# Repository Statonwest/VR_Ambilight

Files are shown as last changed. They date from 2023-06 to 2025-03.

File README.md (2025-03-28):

## Introduction

The VR Ambilight is a project that enhances the immersive experience of virtual reality (VR) by creating dynamic ambient lighting that synchronizes with the on-screen content. This guide will walk you through the process of building your own VR Ambilight system.

V1

It performs exceptionally well for games that feature vibrant colors, like Beat Saber.

## Features

Dynamic ambient lighting synchronized with VR content.

Adjustable color and brightness settings.

Support for Valve Index.

## Materials

Arduino Nano

WS2812b Individually Addressable led Strip 144Pixels/m

Soldering equipment

Defusion sheet

---
Alternative 3D printed diffuser:

Clear filament

Paper

Glue

## Wiring Diagram

Ensure that the LED strip you are using operates at a voltage of **5V**.
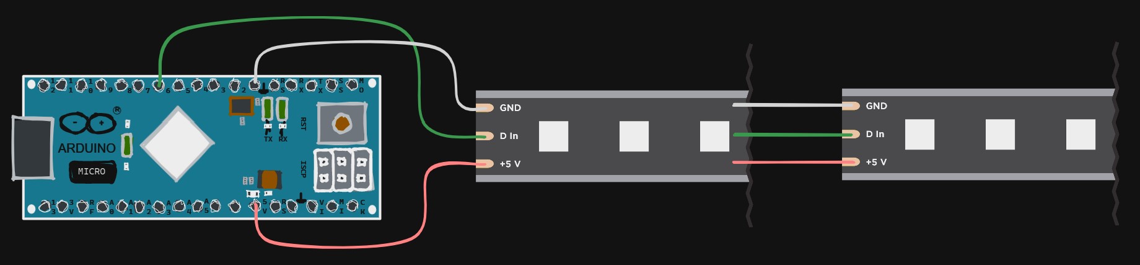
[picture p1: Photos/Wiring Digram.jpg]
Wiring Digram

Typically, for larger LED strip setups, it would require a separate power supply unit (PSU). However, in this case, the number of LEDs is small enough to be powered directly from the Arduino board itself.

## Arduino Setup

Download and install the Arduino IDE from the official Arduino website (https://www.arduino.cc/en/software).

Install the [FastLED libruary](https://github.com/FastLED/FastLED/releases).

Clone or download the project files from the GitHub repository:
[VR_Ambient_light.ino](https://github.com/Statonwest/VR_Ambilight/blob/4264298c710a5be8f2513a294410e2fc3ae0b779/VR_Ambient_light.ino)

The original repository can be found here.
[adalight.ino](https://github.com/hyperion-project/hyperion.ng/blob/master/assets/firmware/arduino/adalight/adalight.ino)

## Building the VR Ambilight

Cut two LED strips, each with 9 LEDs.

Solder the two individual strips together using wire lengths that are long enough to route around to each side of the face gasket.

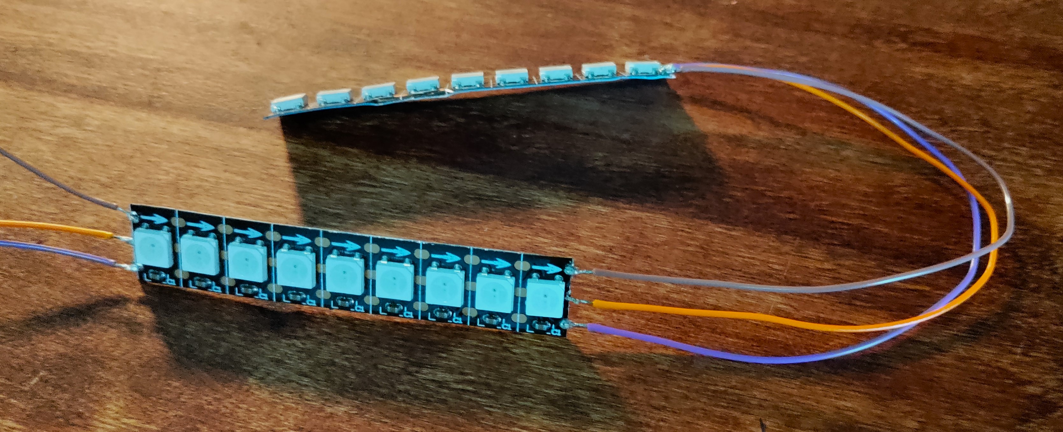
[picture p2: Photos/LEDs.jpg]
Leds


Connect the data line, GND, and the 5V of the LED strip to the Arduino. Connect the DIN (data input) pin of the LED strip to digital pin 6 on the Arduino.

Double-check all the connections to ensure they are secure.

Position the LED strip on the sides of your face gasket, ensuring an even distribution of light. Refer to the image below for reference:

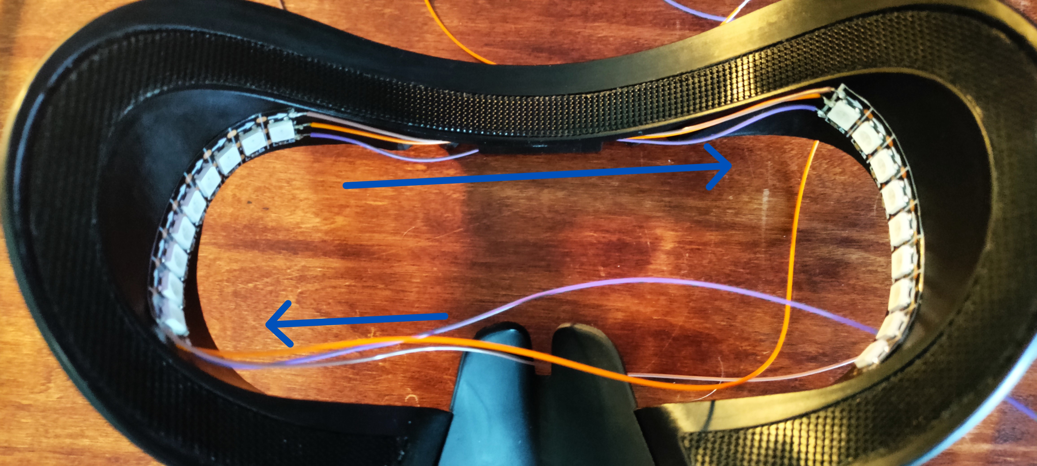
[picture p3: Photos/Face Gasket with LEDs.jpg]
Face Gasket wireing


Choose a wire routing method that works best for you. I opted to route the wires from underneath and over the top of the gasket, but there are other possible arrangements. Adjust your Prismatik settings accordingly to match your wire placement. 

Mount the Arduino Nano securely at the front of the index. Connect the Arduino Nano to the USB port for power and data transmission.

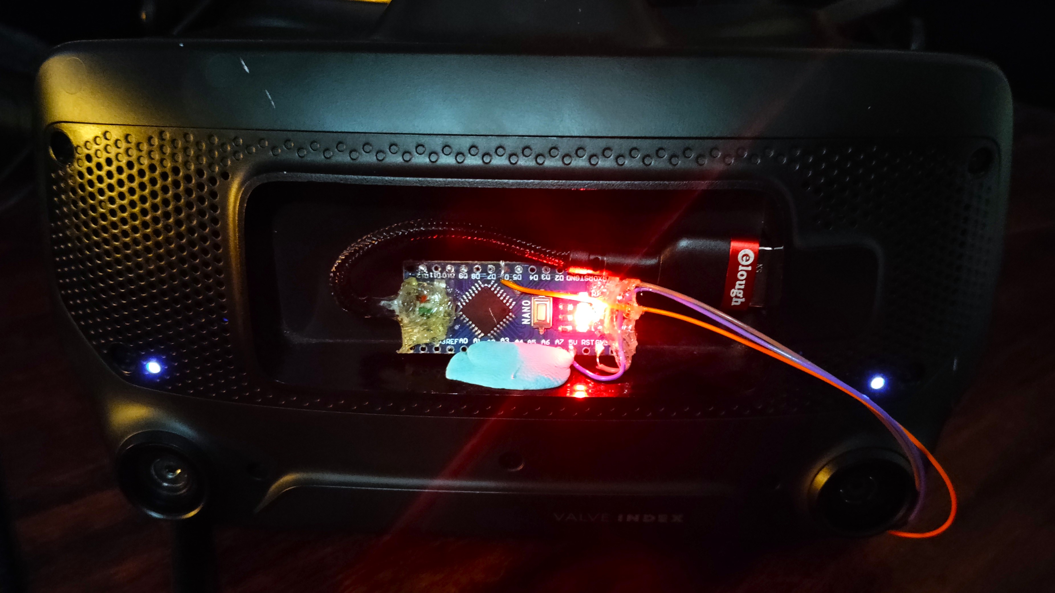
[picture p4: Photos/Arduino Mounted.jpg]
Arduino mounted


### Finer density LED Strips by [OfficerSkidmark](https://github.com/OfficerSkidmark)

![Dense Leds Strip](https://private-user-images.githubusercontent.com/110629277/324322049-5840d202-70ce-44e8-97b2-7244db645ca2.jpg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)

Officer Skidmark used 1,035 LEDs rather than the WS2812b. This provides a much higher resolution while reducing power draw and decreasing the brightness to a more appropriate level.

![Dens Led Strip](https://private-user-images.githubusercontent.com/110629277/323023932-c4211543-2685-4ae9-8bd2-9ce1fb209e6c.jpg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)

## Diffusion Sheet

Cut out the diffusion sheet using the provided [Diffusion Template](https://github.com/Statonwest/VR_Ambilight/blob/3fd8a4334da56437a4c84d81b834a9e21e1f1194/Diffusion%20sheet%20template.png). I used an old display's diffusion and polarizing sheets.

Obtain two polarizing layers and place them parallel to each other. On top of these layers, position the diffusion sheet for optimal results. The order of arrangement should be as follows: "Vertical polarizing filter," "Horizontal polarizing filter," and "Diffusion Sheet."

Cut the tab off the middle sheet and hold all the layers together by using a small amount of tape along the edges.

Fold the tab and secure it with a dab of hot glue. Please note that the diffusion sheet may not easily stick to the glue, so scuff it up a bit before applying the adhesive.
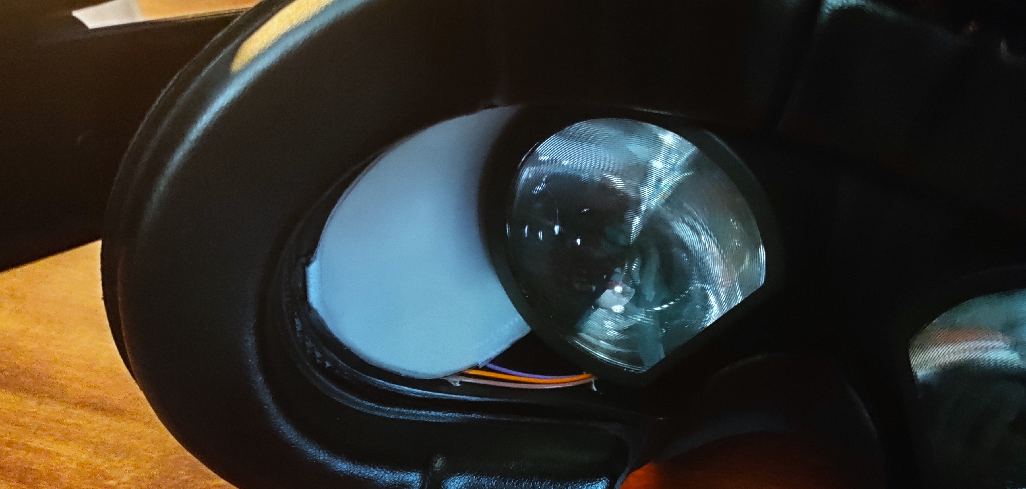
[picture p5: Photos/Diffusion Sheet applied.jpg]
Diffusion Sheet Ex


The bent tab provides a bit of "spring" action, allowing the filter to move along with the lenses to accommodate different [IPDs](https://en.wikipedia.org/wiki/Pupillary_distance)

## Alternative 3D Printed Diffuser by [Nemernemer](https://github.com/Nemernemer)

The 3D printed diffuser version was designed to provide better color-depth and ease of maintenance.

Both an STL and a Step file have been provided for printing and modification. Mirror the diffuser for the left side.

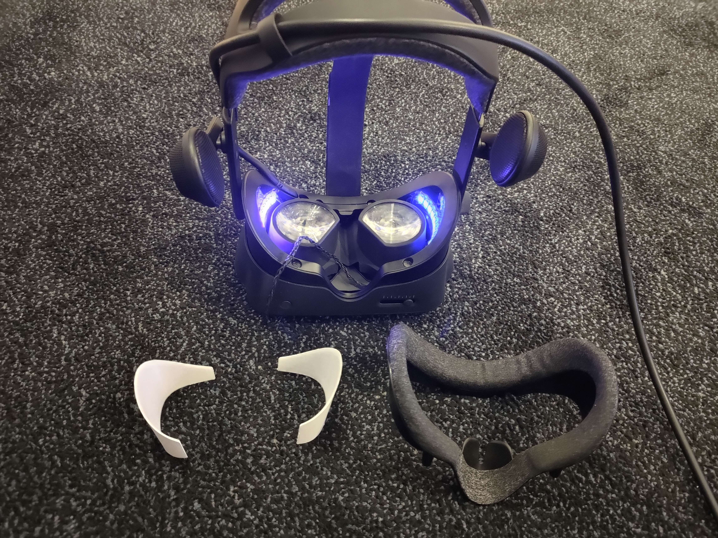
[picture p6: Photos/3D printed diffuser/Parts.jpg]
Parts


The diffusers are held in place by the face gasket and silicone membrane around the lenses.
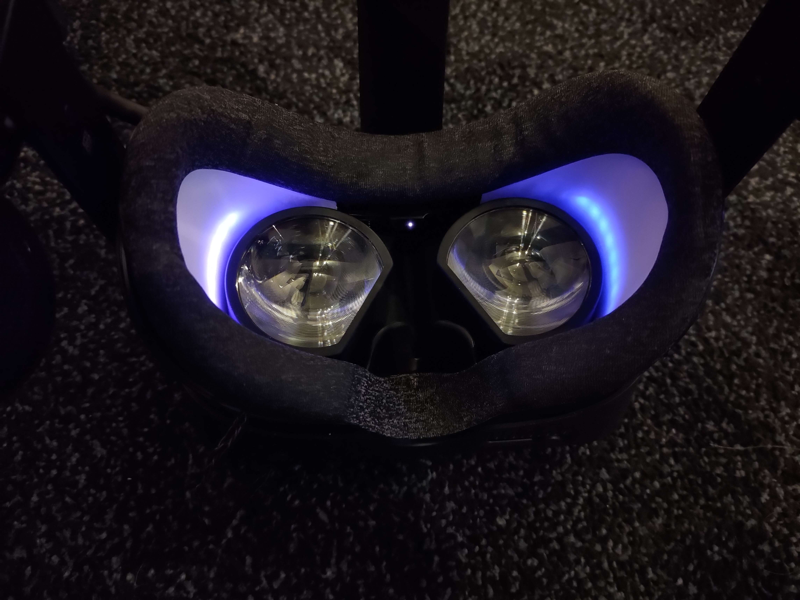
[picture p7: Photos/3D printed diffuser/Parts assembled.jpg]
Parts assembled


Instead of mounting the LEDs to the face gasket, they are instead glued to the headset, pushed up against the edge on each side.
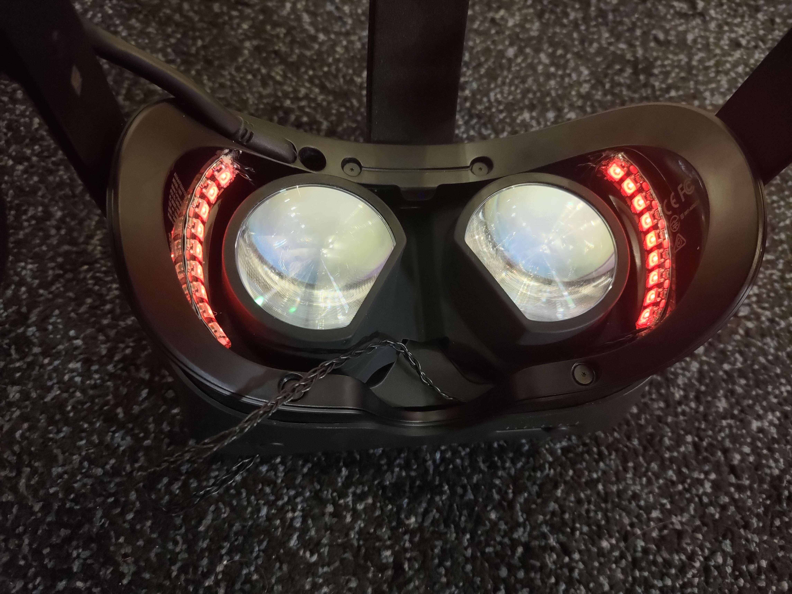
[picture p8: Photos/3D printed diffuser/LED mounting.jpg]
Alternative LED mounting


Glue more layers of paper onto the outside of the 3D print for more diffusion and light reduction. This example uses 2 layers of paper, allowing Prismatik to run at 50% brightness or 7 bits worth of color depth, resulting in less flashing.
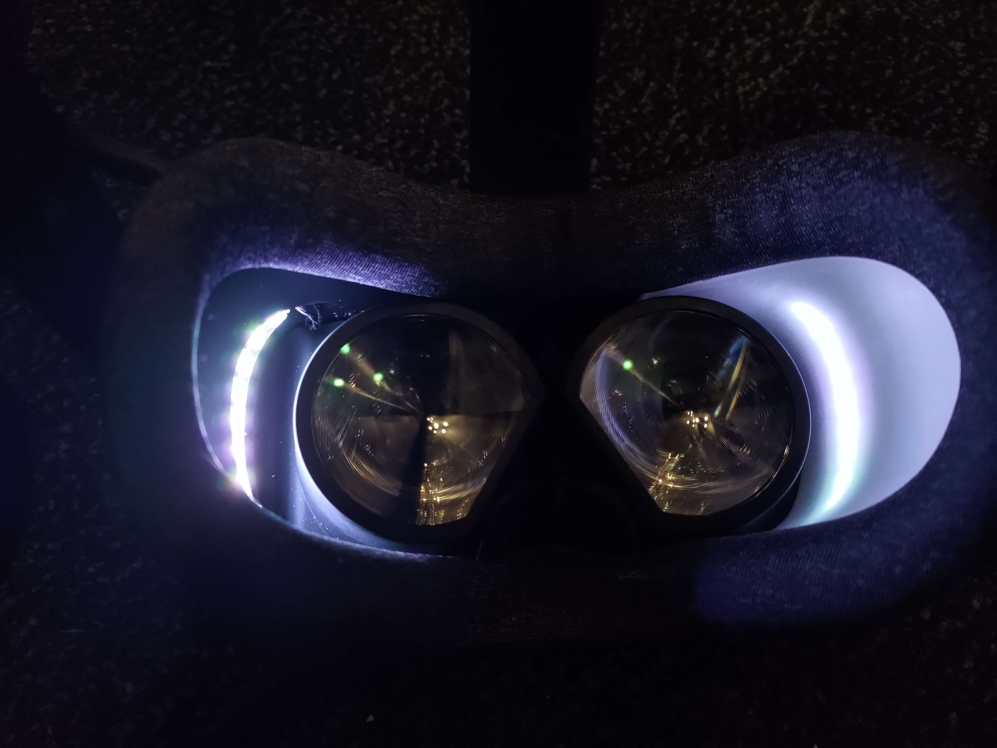
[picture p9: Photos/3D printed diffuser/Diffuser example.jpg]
Diffuser example


Notes for the 3D print in example:
- Filament: Clear ABS
- Extrusion width: 0.86 (0.6 nozzle)
- Layer height: 0.16  (smaller layers recommended to avoid layers concentrating light into lines)
- Temperature: Below manufacturer recommendation for a matte finish

## Sampler / Screen Capture
[OpenVR Ambient Light](https://github.com/Rectus/openvr_ambient_light) is the control software for ambient LED lighting in virtual reality headsets. Unlike most other control software that sample the desktop, OpenVR Ambient Light directly samples the VR headset view. This provides accurate light estimation based on the content actually shown by the headset, and prevents other windows on the desktop from interfering.

## <strike>Screen Capture (Legacy)
[Prismatik](https://github.com/psieg/Lightpack/releases) serves as the primary software solution for our guild's needs, although there are several alternative options available, such as [Firefly Luciferin](https://github.com/sblantipodi/firefly_luciferin). Firefly is recognized for its lower computational resource requirements.

The software is used for screen content capture and data transmission to the Arduino.

Launch Prismatik and go through the initial setup process. Follow the on-screen instructions to configure the display settings.
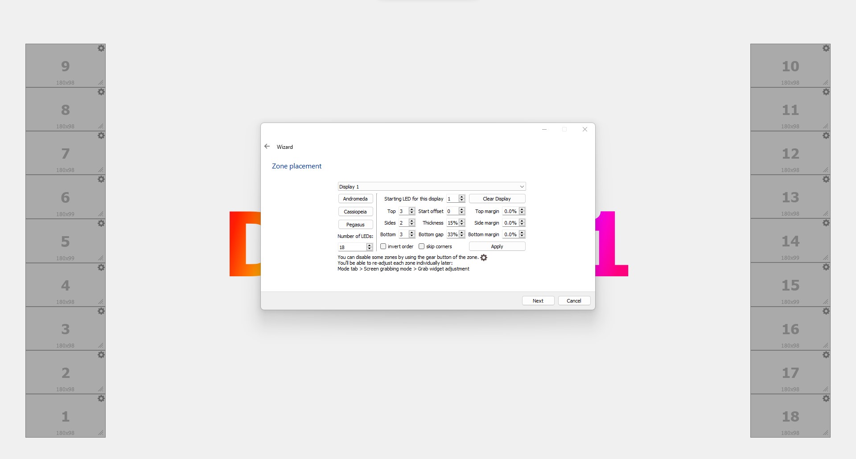
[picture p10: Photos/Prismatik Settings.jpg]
Prismatik settings


Configure the output settings to match your Arduino connection. Select the correct COM port corresponding to the Arduino Nano.

Adjust any additional settings in Prismatik according to your preferences, such as brightness (e.g. 10%), and capture area (e.g. Screen 1).
</strike>

## To do

- [x] Better diffusion

- [ ] Better Mount for arduino

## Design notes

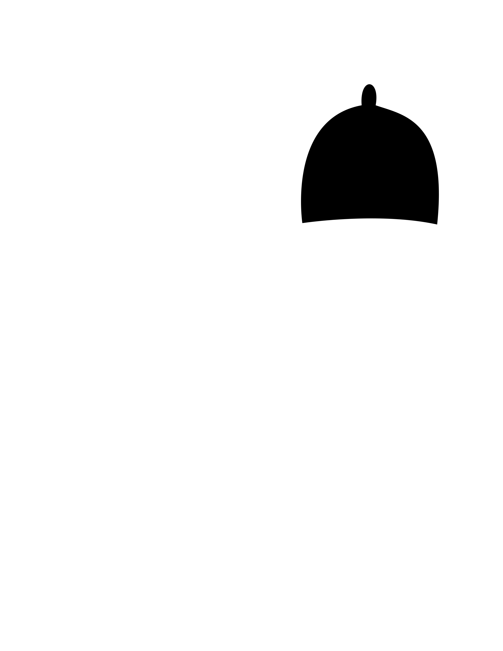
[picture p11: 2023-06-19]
Diffusion sheet template.png

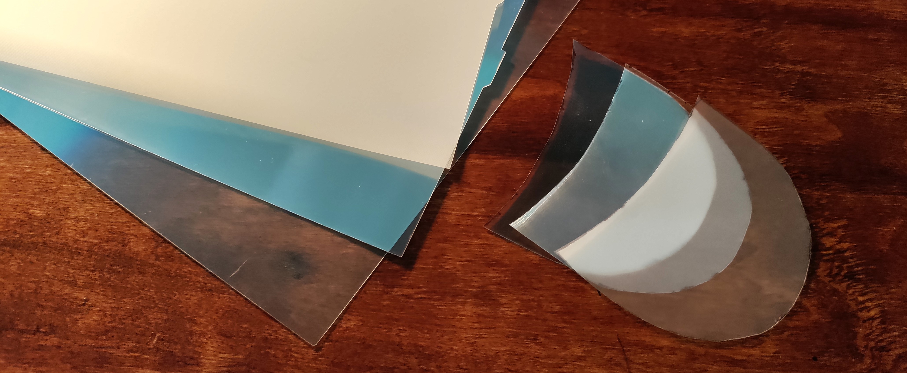
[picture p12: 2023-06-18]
Photos/Diffusion Sheets.jpg

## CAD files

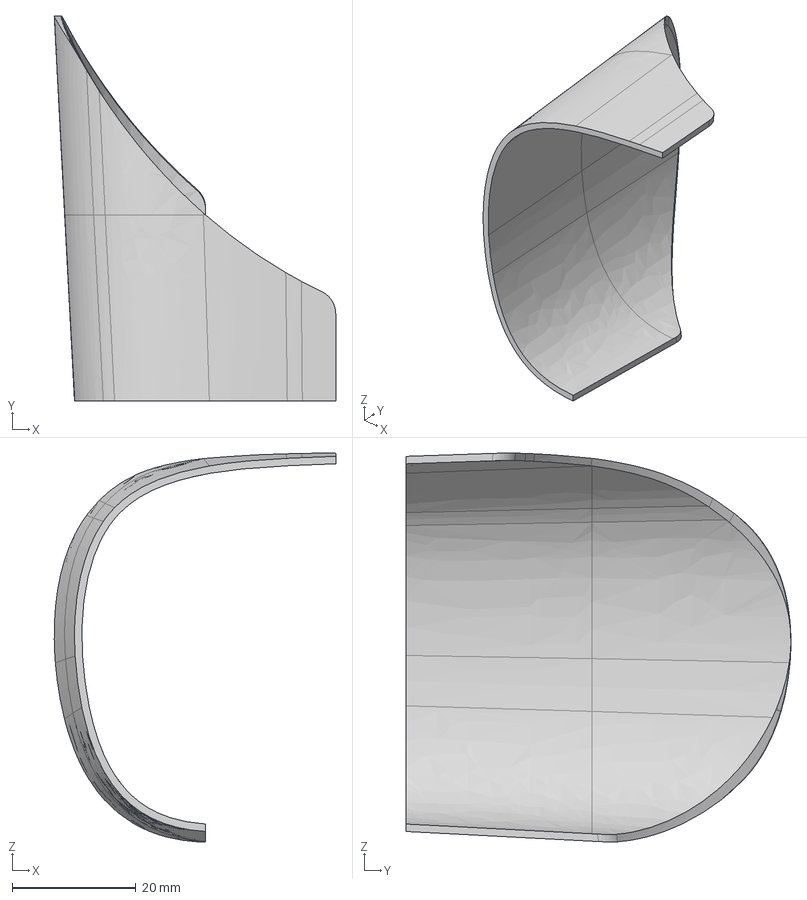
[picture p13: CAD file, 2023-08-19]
3D files/Diffuser.step
45.4 x 62.1 x 62.8 mm

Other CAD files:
3D files/Diffuser.stl

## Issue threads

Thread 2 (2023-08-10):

Potential improvements

Nemernemer, 2023-08-10:
Hello!

Apologies if this is the wrong way to go about this, I am not used to Github etiquette.
I followed your project, and I think I have some improvements.

1: Instead of mounting the LEDs on the face gasket, I found it more convenient to instead place them against the raised edge on the unit itself. This had both the benefit of the LEDs being more in view, and the convenience of being able to remove the gasket for cleaning without taking along the electronics. I am using the silicone cast version of WS2812Bs, which helps protect against accidental scratching when removing the face gasket.

2: Instead of using a diffusion sheet, I designed a 3d-print which you make out of a translucent filament (in my case clear ABS) and glue two layers of paper onto. This too is just held in place between the gasket and the silicone surrounding the lenses. This allowed me to run the LEDs significantly brighter (50%) without them blinding the user, which in turn gives a considerably higher color depth, mitigating a lot of the erratic flashing experienced at 10-25%. (Unfortunately this takes away ~2mm from the upper eye distance adjustment, but does not prohibit the back and forth adjustment.)

I have attached two images of my implementation, and the STEP file for the 3D print, if that is of interest.

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

(Diffuser printed at 0.86mm line widths with a 0.6mm nozzle, creating two solid walls. 0.16 layer height)
[Diffuser.zip](https://github.com/Statonwest/VR_Ambilight/files/12317541/Diffuser.zip)

Statonwest, 2023-08-11:
Thanks for reaching out. I dig the improvements. This is my first real repository so the etiquette is new to me to.If you can clone the repo, add your changes to it, and then submit a merge request, I can add it to the main branch. That way you'll also get the credit.

Statonwest, 2023-08-11:
Thanks for reaching out. I dig the improvements. This is my first real repository so the etiquette is new to me to.If you can clone the repo, add your changes to it, and then submit a merge request, I can add it to the main branch. That way you'll also get the credit.

Closed 2023-08-14.

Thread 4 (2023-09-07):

Different Screen Capture Software

elbrodark, 2023-09-07:
Hi,
Nice Project, the mounting inside the headset works perfectly via the 3dprinted Diffuser, i glued the LED directly to the Diffuser, so nothing gets "broken" inside the Headset.

For the Software i switched from "Prismatik" to "Firefly Luciferin" (https://github.com/sblantipodi/firefly_luciferin) cause it´s not so extremly ressource hungry like Prismatik and it also works via wifi.

Statonwest, 2023-09-07:
Thanks for your input. Firefly has been added.

Closed 2023-09-07.

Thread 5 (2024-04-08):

Finer density LED strips

OfficerSkidmark, 2024-04-08:
not an "Issue" but something I'm working on for this, couldnt figure out how best to highlight the project. i got this running on my index this weekend and one thing i thought it to lack was a resolution with only 9 LEDs on each side. I'm prototyping a new set of LED strips that has 20 leds on each side. i am using the 4684 -ws2812B leds from adafruit which are significantly smaller than the normal ws2812 leds used. this allowed me to add a lot of more leds to each side. another thing with the smaller size is they arnt as bright, which is another thing i had issues with. the intended leds are BRIGHT! after some math the leds i chose have max 12ma, x40 you get 480ma.
arduino nano base level is roughly 200ma and with a safety margin of x2, that's 400ma. the usb3.0 in the frunk should be .9a or 900ma so this should be under its max draw.  math works out. we shall see how this works

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

Statonwest, 2024-04-09:
Looks promising. Excited to see how it works out.

OfficerSkidmark, 2024-04-16:
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

Board and LEDs have arrived and mostly assembled. Got the nano and Ambilight software rolling too. Need some double side tape to move forward

OfficerSkidmark, 2024-04-22:
Finally got them installed into my headset!
Th added resolution is a warm welcome and feel they have a better color. If I wanted more resolution I found 1035 LEDs that are even smaller. But for now I think I'm going to roll with this. Any video I make is too large but it looks good. Now if only I can get the weird mask from beat saber to go away and I can have full view
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

![Uploading PXL_20240421_191941097.jpg …]()

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

Statonwest, 2025-03-28:
That turned out amazing. I have added the basics to the doc. If you have more details to add could you put into a merge request?

Closed 2025-03-28.

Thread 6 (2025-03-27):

Direct SteamVR sampling software

Rectus, 2025-03-27:
Thanks for this guide. I built it with the 3D printed diffuser (with some modifications) and it works really well.

The current solution using a control software that captures the screen is very clunky and prevents using the desktop. To solve it, I wrote a program that directly samples the compositor output from SteamVR instead. It starts and stops with SteamVR, and runs in the background. It does most of the processing with a fast compute shader so it should have a minimal performance impact.

https://github.com/Rectus/openvr_ambient_light

If there are any features you'd like to see added, I'm always open to suggestions.

Statonwest, 2025-03-28:
This is exactly what I've been wanting! I'll let you know if I have any suggestions. Also, I've added it to the docs. If there are any updates or modifications you'd like to include, just send a merge request.

Closed 2025-03-28.

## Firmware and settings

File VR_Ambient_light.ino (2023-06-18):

#include "FastLED.h"

#define ANALOG_MODE_AVERAGE  0
#define ANALOG_MODE_LAST_LED 1

/**************************************
   S E T U P

   set following values to your needs
 **************************************/

#define INITIAL_LED_TEST_ENABLED true
#define INITIAL_LED_TEST_BRIGHTNESS 32  // 0..255
#define INITIAL_LED_TEST_TIME_MS 500  // 10..

// Number of leds in your strip. set to "1" and ANALOG_OUTPUT_ENABLED to "true" to activate analog only
// As of 26/1/2017:
// 582 leaves ZERO bytes free and this
// 410 is ok
// tested with 500 leds and is fine (despite the warning)
#define MAX_LEDS 18

// type of your led controller, possible values, see below
#define LED_TYPE WS2812B 

// 3 wire (pwm): NEOPIXEL BTM1829 TM1812 TM1809 TM1804 TM1803 UCS1903 UCS1903B UCS1904 UCS2903 WS2812 WS2852
//               S2812B SK6812 SK6822 APA106 PL9823 WS2811 WS2813 APA104 WS2811_40 GW6205 GW6205_40 LPD1886 LPD1886_8BIT 
// 4 wire (spi): LPD8806 WS2801 WS2803 SM16716 P9813 APA102 SK9822 DOTSTAR

// For 3 wire led stripes line Neopixel/Ws2812, which have a data line, ground, and power, you just need to define DATA_PIN.
// For led chipsets that are SPI based (four wires - data, clock, ground, and power), both defines DATA_PIN and CLOCK_PIN are needed

// DATA_PIN, or DATA_PIN, CLOCK_PIN
#define LED_PINS 6        // 3 wire leds
//#define LED_PINS 6, 13  // 4 wire leds

#define COLOR_ORDER GRB  // colororder of the stripe, set RGB in hyperion

#define OFF_TIMEOUT 15000    // ms to switch off after no data was received, set 0 to deactivate

// analog rgb uni color led stripe - using of hyperion smoothing is recommended
// ATTENTION  this pin config is default for atmega328 based arduinos, others might work to
//            if you have flickering analog leds this might be caused by unsynced pwm signals
//            try other pins is more or less the only thing that helps
#define ANALOG_OUTPUT_ENABLED false
#define ANALOG_MODE           ANALOG_MODE_LAST_LED  // use ANALOG_MODE_AVERAGE or ANALOG_MODE_LAST_LED
#define ANALOG_GROUND_PIN     8                     // additional ground pin to make wiring a bit easier
#define ANALOG_RED_PIN        9
#define ANALOG_GREEN_PIN      10
#define ANALOG_BLUE_PIN       11

// overall color adjustments
#define ANALOG_BRIGHTNESS_RED   255              // maximum brightness for analog 0-255
#define ANALOG_BRIGHTNESS_GREEN 255              // maximum brightness for analog 0-255
#define ANALOG_BRIGHTNESS_BLUE  255              // maximum brightness for analog 0-255

#define BRIGHTNESS 150                       // maximum brightness 0-255
#define DITHER_MODE BINARY_DITHER           // BINARY_DITHER or DISABLE_DITHER
#define COLOR_TEMPERATURE CRGB(255,255,255) // RGB value describing the color temperature
#define COLOR_CORRECTION  TypicalLEDStrip   // predefined fastled color correction
//#define COLOR_CORRECTION  CRGB(255,255,255) // or RGB value describing the color correction

// Baudrate, higher rate allows faster refresh rate and more LEDs
//#define serialRate 460800      // use 115200 for ftdi based boards
#define serialRate 115200      // use 115200 for ftdi based boards
//#define serialRate 500000         // use 115200 for ftdi based boards


/**************************************
   A D A L I G H T   C O D E

   no user changes needed
 **************************************/

// Adalight sends a "Magic Word" (defined in /etc/boblight.conf) before sending the pixel data
uint8_t prefix[] = {'A', 'd', 'a'}, hi, lo, chk, i;

unsigned long endTime;

// Define the array of leds
CRGB leds[MAX_LEDS];

// set rgb to analog led stripe
void showAnalogRGB(const CRGB& led) {
  if (ANALOG_OUTPUT_ENABLED) {
    byte r = map(led.r, 0,255,0,ANALOG_BRIGHTNESS_RED);
    byte g = map(led.g, 0,255,0,ANALOG_BRIGHTNESS_GREEN);
    byte b = map(led.b, 0,255,0,ANALOG_BRIGHTNESS_BLUE);
    analogWrite(ANALOG_RED_PIN  , r);
    analogWrite(ANALOG_GREEN_PIN, g);
    analogWrite(ANALOG_BLUE_PIN , b);
  }
}

// set color to all leds
void showColor(const CRGB& led) {
  #if MAX_LEDS > 1 || ANALOG_OUTPUT_ENABLED == false
  LEDS.showColor(led);
  #endif
  showAnalogRGB(led);
}

// switch of digital and analog leds
void switchOff() {
  #if MAX_LEDS > 1 || ANALOG_OUTPUT_ENABLED == false
  memset(leds, 0, MAX_LEDS * sizeof(struct CRGB));
  FastLED.show();
  #endif
  showAnalogRGB(leds[0]);
}

// function to check if serial data is available
// if timeout occured leds switch of, if configured
bool checkIncommingData() {
  boolean dataAvailable = true;
  while (!Serial.available()) {
    if ( OFF_TIMEOUT > 0 && endTime < millis()) {
      switchOff();
      dataAvailable = false;
      endTime = millis() + OFF_TIMEOUT;
    }
  }

  return dataAvailable;
}

// main function that setups and runs the code
void setup() {
  Serial.begin(serialRate);

  // analog output
  if (ANALOG_OUTPUT_ENABLED) {
    // additional ground pin to make wiring a bit easier
    pinMode(ANALOG_GROUND_PIN, OUTPUT);
    digitalWrite(ANALOG_GROUND_PIN, LOW);
    pinMode(ANALOG_BLUE_PIN , OUTPUT);
    pinMode(ANALOG_RED_PIN  , OUTPUT);
    pinMode(ANALOG_GREEN_PIN, OUTPUT);
  }

  int ledCount = MAX_LEDS;
  if (ANALOG_OUTPUT_ENABLED == true && ANALOG_MODE == ANALOG_MODE_LAST_LED) {
    ledCount--;
  }

  #if MAX_LEDS > 1 || ANALOG_OUTPUT_ENABLED == false
    FastLED.addLeds<LED_TYPE, LED_PINS, COLOR_ORDER>(leds, ledCount);
  #endif
  
  // color adjustments
  FastLED.setBrightness ( BRIGHTNESS );
  FastLED.setTemperature( COLOR_TEMPERATURE );
  FastLED.setCorrection ( COLOR_CORRECTION );
  FastLED.setDither     ( DITHER_MODE );

  // initial RGB flash
  #if INITIAL_LED_TEST_ENABLED == true
  for (int v=0;v<INITIAL_LED_TEST_BRIGHTNESS;v++)
  {
    showColor(CRGB(v,v,v));  
    delay(INITIAL_LED_TEST_TIME_MS/2/INITIAL_LED_TEST_BRIGHTNESS);
  }
 
  for (int v=0;v<INITIAL_LED_TEST_BRIGHTNESS;v++)
  {
    showColor(CRGB(v,v,v));  
    delay(INITIAL_LED_TEST_TIME_MS/2/INITIAL_LED_TEST_BRIGHTNESS);
  }
  #endif
  showColor(CRGB(0, 0, 0));

  Serial.print("Ada\n"); // Send "Magic Word" string to host
  Serial.println("Ada: LED num: " +  String(FastLED.size())); //Return number of LEDs configured

  boolean transmissionSuccess;
  unsigned long sum_r, sum_g, sum_b;

  // loop() is avoided as even that small bit of function overhead
  // has a measurable impact on this code's overall throughput.
  for(;;) {
    // wait for first byte of Magic Word
    for (i = 0; i < sizeof prefix; ++i) {
      // If next byte is not in Magic Word, the start over
      if (!checkIncommingData() || prefix[i] != Serial.read()) {
        i = 0;
      }
    }

    // Hi, Lo, Checksum
    if (!checkIncommingData()) continue;
    hi = Serial.read();
    if (!checkIncommingData()) continue;
    lo = Serial.read();
    if (!checkIncommingData()) continue;
    chk = Serial.read();

    // if checksum does not match go back to wait
    if (chk != (hi ^ lo ^ 0x55)) continue;

    memset(leds, 0, MAX_LEDS * sizeof(struct CRGB));
    transmissionSuccess = true;
    sum_r = 0;
    sum_g = 0;
    sum_b = 0;

    int num_leds = min ( MAX_LEDS, (hi<<8) + lo + 1 );

    // read the transmission data and set LED values
    for (int idx = 0; idx < num_leds; idx++) {
      byte r, g, b;
      if (!checkIncommingData()) {
        transmissionSuccess = false;
        break;
      }
      r = Serial.read();
      if (!checkIncommingData()) {
        transmissionSuccess = false;
        break;
      }
      g = Serial.read();
      if (!checkIncommingData()) {
        transmissionSuccess = false;
        break;
      }
      b = Serial.read();
      leds[idx].r = r;
      leds[idx].g = g;
      leds[idx].b = b;
      #if ANALOG_OUTPUT_ENABLED == true && ANALOG_MODE == ANALOG_MODE_AVERAGE
          sum_r += r;
          sum_g += g;
          sum_b += b;
      #endif
    }

    // shows new values
    if (transmissionSuccess) {
      endTime = millis() + OFF_TIMEOUT;
      #if MAX_LEDS > 1 || ANALOG_OUTPUT_ENABLED == false
      FastLED.show();
      #endif

      #if ANALOG_OUTPUT_ENABLED == true
        #if ANALOG_MODE == ANALOG_MODE_LAST_LED
          showAnalogRGB(leds[MAX_LEDS-1]);
        #else
          showAnalogRGB(CRGB(sum_r/MAX_LEDS, sum_g/MAX_LEDS, sum_b/MAX_LEDS));
         #endif
      #endif
    }
  }
} // end of setup

void loop() {
  // Not used. See note in setup() function.
}
